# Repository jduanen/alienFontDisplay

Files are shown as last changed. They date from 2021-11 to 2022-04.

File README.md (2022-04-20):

# alienFontDisplay
Display made of six eight-segment EL display units with per-display custom driver board and controller.

Scrolling display board that displays whatever string is published on a given MQTT channel over WiFi.

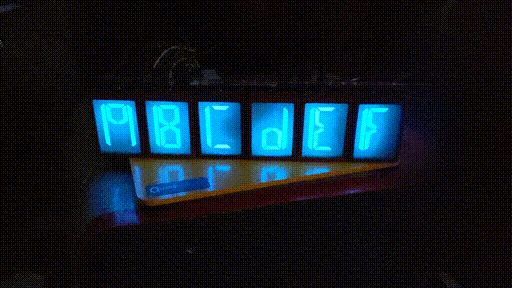
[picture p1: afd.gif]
Scroll Test


These displays were used in Russian tanks and missile launch consoles.

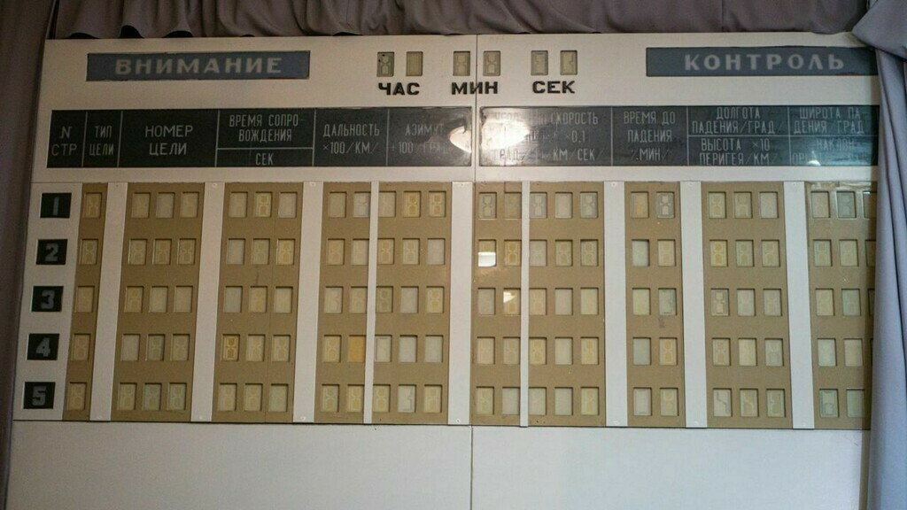
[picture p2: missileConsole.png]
Missile Console


## TBD
* Design 225VAC 400Hz inverter that can supply ?mA (?W)
* BOM
* WiFi interface board
* Firmware
* Tests
* Example code
* Documentation

### Display Pinout
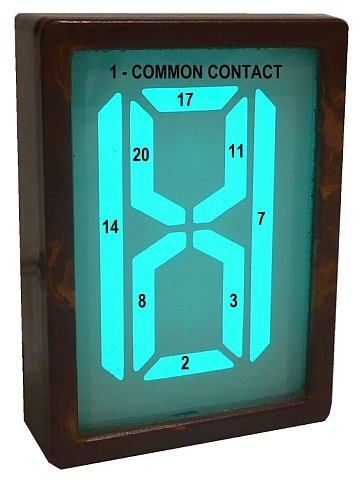
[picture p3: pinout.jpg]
EL Display Pinout


### Alphanumeric Font
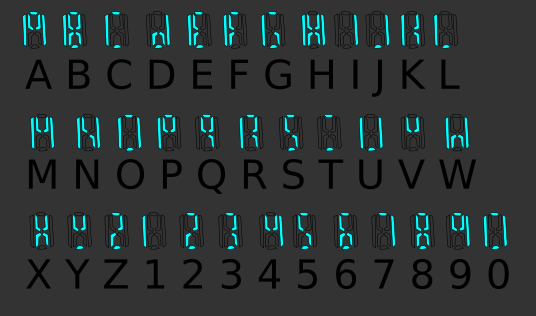
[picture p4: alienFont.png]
Alien Font


### Single Display and Driver Board
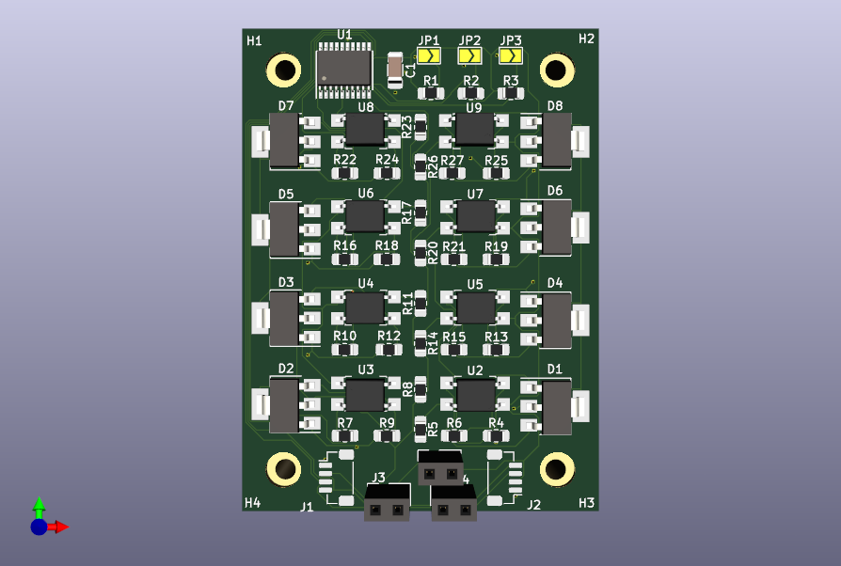
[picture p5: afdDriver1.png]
Driver Board view #1

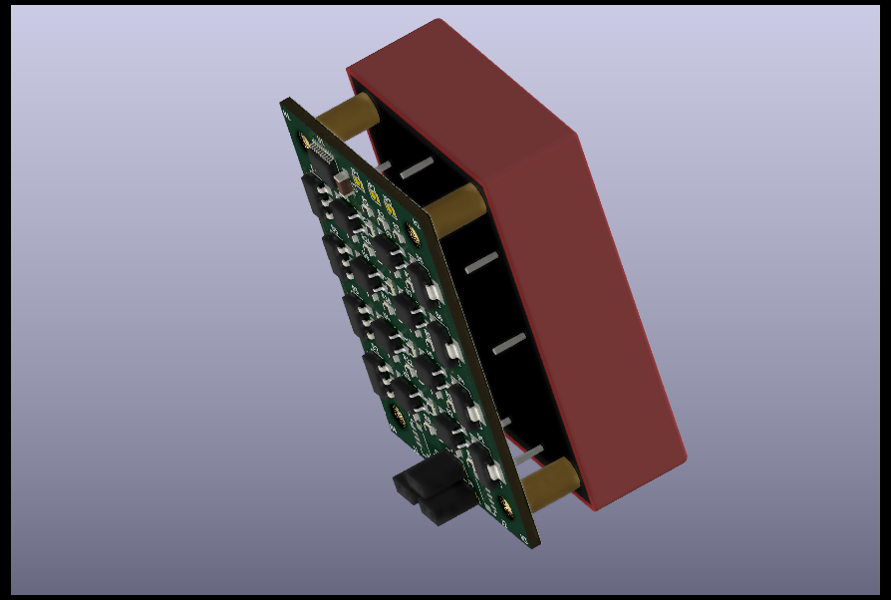
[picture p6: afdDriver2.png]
Driver Board view #2


### Driver PCB
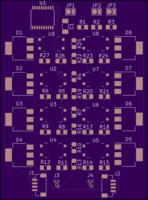
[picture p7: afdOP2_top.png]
Driver Board Top

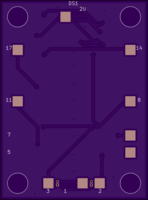
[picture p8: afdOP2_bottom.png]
Driver Board Bottom

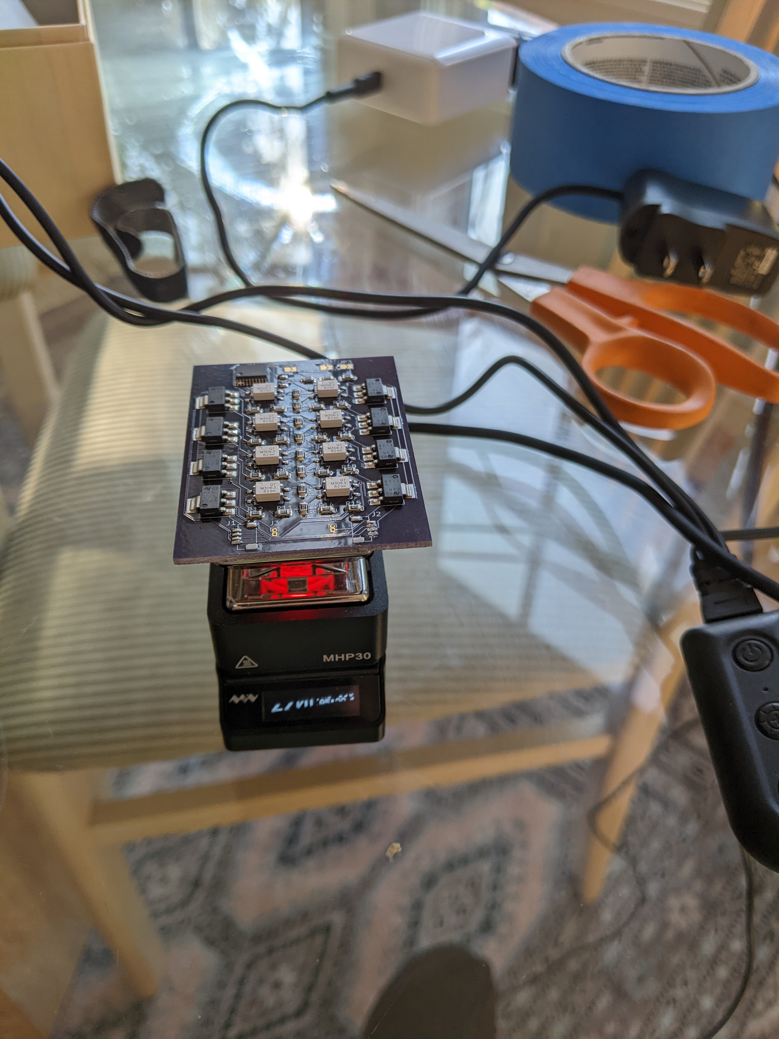
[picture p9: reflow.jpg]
Assembling Board

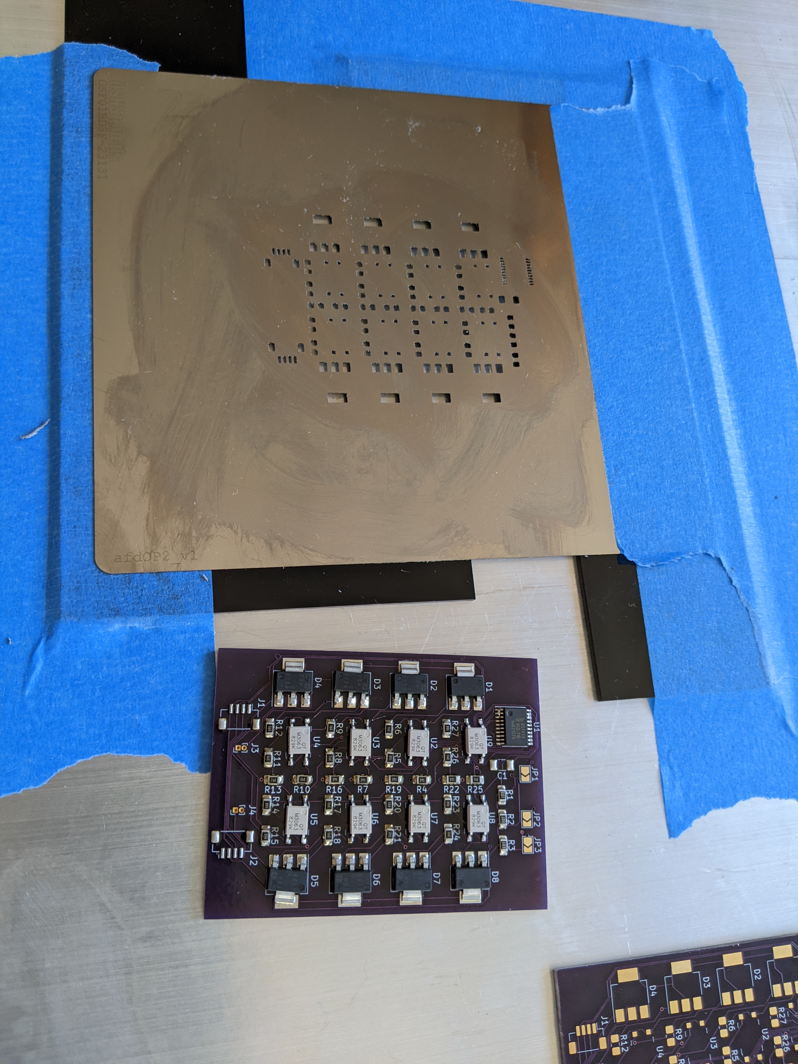
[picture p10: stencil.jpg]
Assembled Board


### Schematic
Driver Board Schematic

# EL Displays

## IEL-O-VI C63.396.208-02
* Blue, Alien Font, Russian/Soviet Electroluminescent Display
* [0-9] and [A-Z] (after a fashion)
  - some characters are lower case and some are missing strokes
    * in particular, there isn't a center vertical stroke, so "T" and "I" are not so great
  - seems to have been designed for Cyrillic characters
* pinout
  - 1: common
  - 2: bottom horizontal (S)
  - 3: bottom right angled (M)
  - 5: n/c?
  - 7: left vertical (L)
  - 8: bottom left angled (M)
  - 11: top right angled (M)
  - 14: left vertical (L)
  - 17: top horizontal (S)
  - 20: top left angled (M)
* per-segment capacitance (estimates)
  - S (2x): 55 pFd
  - M (4x): 90 pFd
  - L (2x): 170 pFd

# Power Supply Design

* Specs
  - 220VAC @ 400Hz
  - 0.5-3mA per display
    * four displays: 12mA (max)
    * six displays: 18mA (max)
* Design alternatives
  - drive audio amp into (CT?) step-up transformer
  - DC boost converter into H-Bridge

=========================

* notes
  - ~200V @ 400Hz
  - not squarewave -- filter or triangle wave for constant dv/dt
  - less bright at 50Hz, but last longer
  - need current limiting resistor if power source has low internal resistance
    * e.g., 330K ohm @ 220V @ 50Hz
  - 500 Hrs lifespan
  - sine/square voltage up to 250V and 400Hz-5KHz
  - decay time fractions of msec
  - at least 6usec pulse
  - no loss of brightness in pulses of 100usec at constant duty cycle
  - most of drop in brightness occurs in first 200 hours of operation
    * relatively flat after that
  - for best lifetime, maintain constant frequency and reduce voltage
  - use current limiting resistor for supplies with internal resistance less than 1Kohm
  - add 0.03-0.05ufd caps in parallel with electrodes to improve reliability
  - nomenclature
    * I: indicator
    * EL: electroluminescent
    * color
      - O: one color
      - M: multicolor
      - P: raster
    * size (13x sizes)
      - VI: 34x40mm
      - II: 13x35mm
      - IV: 18x26mm
      - 
    * number of dots indicate brightness
  - IEL-0-VI-101-246: 19x segment starburst with bar above and left and right commas
  - constant power mode
    * 220V @ 400Hz
  - constant brightness mode
    * 175-250V @ 1200Hz -- increases with service life
  - 0.5-3 mA current
  - DC will destroy the display
  - can't multiplex displays -- need driver for each segment
  - lifetime drops rapidly with supply frequency >400Hz

* Links
  - https://www.nixology.uk/el-displays/
  - http://www.155la3.ru/electroluminescent.htm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
  - https://www.youtube.com/watch?v=p6mNbgtnFK8
  - http://lampes-et-tubes.info/cd/cd143.php?l=e
  - http://www.nedopc.org/forum/viewtopic.php?f=65&t=11093
  - https://www-nedopc-org.translate.goog/forum/viewtopic.php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

* Sparkfun EL Inverter (COM-10469 retired)
  - input: 12VDC
  - output: 70-110V (90V typ)
  - frequency: 800-3500Hz (2000Hz typ)

* Sparkfun EL Inverter (sourced from Amazon)
  - input: 5VDC
  - output: 225VAC (in afd circuit)
  - frequency: 5-7KHz (in afd circuit)

=======================================================================================
* SmartSocket for Alien Font displays
  - use same protocol on daisy-chained 9600 baud RS232 (3v3?)
    * http://tayloredge.com/reference/Circuits/1386SmartSocket/SmartSockets.pdf
  - build single-sided PCB that fits on back of display units
    * drive each segment individually
    * use common HV PSU
    * use circuits from SparkFun boards as they have been tested and shown to work
  - need to select a PIC to use as the on-board controller
    * PIC18F16Q41: same as PIC18F16Q40 but has an opAmp
    * PIC18F16Q40:
      - 14pin device has six GPIOs on PortA and another six on PortC
      - has 1/2 UARTs
      - 64KB program FLASH, 4KB SRAM, 512B EEPROM
      - 18x GPIO, 2/3x 8b timers, 17x channels of 12b ADC, 2x 8b DACs, 4x DMA
      - 32b CRC with scanner, vectored interrupts, temperature indicator, NCO, PWM/CCP
      - C compiler
        * CCS: http://www.ccsinfo.com -- $200-$500
        * Hi-Tech: http://www.htsoft.com -- bought by Microchip
        * Microchip: http://www.microchip.com -- free student mode
        * MPLAB C18: microchip
        * MikroC: free student version with limits
        * https://www.microchip.com/en-us/development-tool/C18
      - $1.5 at Mouser (in stock)
        * PIC18F16Q40-E/SO
        * https://www.mouser.com/ProductDetail/Microchip/PIC18F16Q40-E-SO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
      - example: https://github.com/microchip-pic-avr-examples/pic18f16q40-quadrature-decoder
        * RA2: UART Tx programmer?
        * RB7: UART Tx
        * RB5: UART Rx
        * RB4, RB6, RA4, RA5, RC0-RC7: GPIO
      - PPS re-mappable input signals can be moved from default locations to other ports
        * UART outputs: DTR1, RTS1, TX1, DTR2, RTS2, TX2, DTR3, RTS3, TX3
        * UART inputs: RX1, CTS1, RX2, CTS2, RX3, CTS3 
      - pin allocation table (default)
        * RB5: RX1
        * RB7: CTS1
        * RC1: RX2
        * RC2: CTS2
        * RC3: RX3
        * RC5: CTS3
  - use shift registers?
  - use I2C port expander?

* display unit dimensions, pin and threaded spacer locations are not consistent across instances

* Use SparkFun EL boards for proof of concept testing

* EL Sequencer v23
  - https://www.sparkfun.com/products/12781
  - http://cdn.sparkfun.com/datasheets/Components/EL/SparkFun_EL_Sequencer_v23.pdf
  - ATMega328P processor on-board
    * use "Arduino Duemilanove or Diecimila" board with FTDI USB dongle
  - Gets HV from Sparkfun EL Inverter
    * not ideal -- need higher voltage and better frequency
  - Drives HV to all segments of all displays
    * EL Escudo Dos pulls display commons to HV_GND
  - D2-D9 used to drive EL_A-EL_H
    * EL_A: pin 2
    * EL_B: pin 3
    * EL_C: pin 7
    * EL_D: pin 8
    * EL_E: pin 11
    * EL_F: pin 14
    * EL_G: pin 17
    * EL_H: pin 20
  - Sends six (active high) TTL signals to EL Escudo Dos to enable each display
    * ADC_0 (JP4:2): display #1
    * ADC_1 (JP4:7): display #2
    * ADC_2 (JP2:8): display #3
    * ADC_3 (JP2:7): display #4
    * ADC_4 (JP2:6): display #5
    * ADC_5 (JP2:5): display #6

* EL Escudo Dos
  - https://www.sparkfun.com/products/10878
  - https://cdn.sparkfun.com/datasheets/Components/EL/EL_Escudo_Dos/EL%20Escudo%20Dos%20v21.pdf
  - Pulls display common lines (pin 1) down to HV_GND
  - EL_H: display #1 ... EL_C: display #6
  - gets HV_GND and TTL display unit selector signals from EL Sequencer
  - all SCRs have common HV connected to their tabs
    * and they have individual outputs to load and ground
  - need to cut HV to tabs and connect them to the display common signals
    * and short all load outputs to HV_GND

* misc
  - mqtt listener
    * mosquitto_sub -t /displays/# -F "%I,%t,%p"
  - commands
    * rssi
    * version
    * reset
    * rate[=<rate>]
    * scrollDelay[=<msecs>]
    * pause[=<msecs>]
    * display[=<str>]
  - e.g., mosquitto_pub -t "/displays/afd/<IPAddr>/cmd" -m "display=abcdefghijklmnopqrstuvwxyz0123456789"

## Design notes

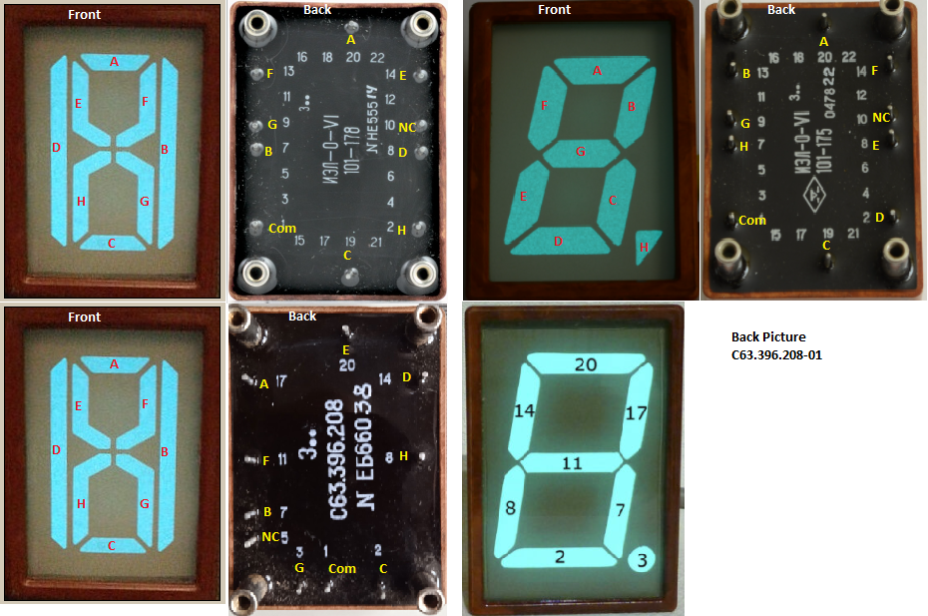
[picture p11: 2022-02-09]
elpanel.png

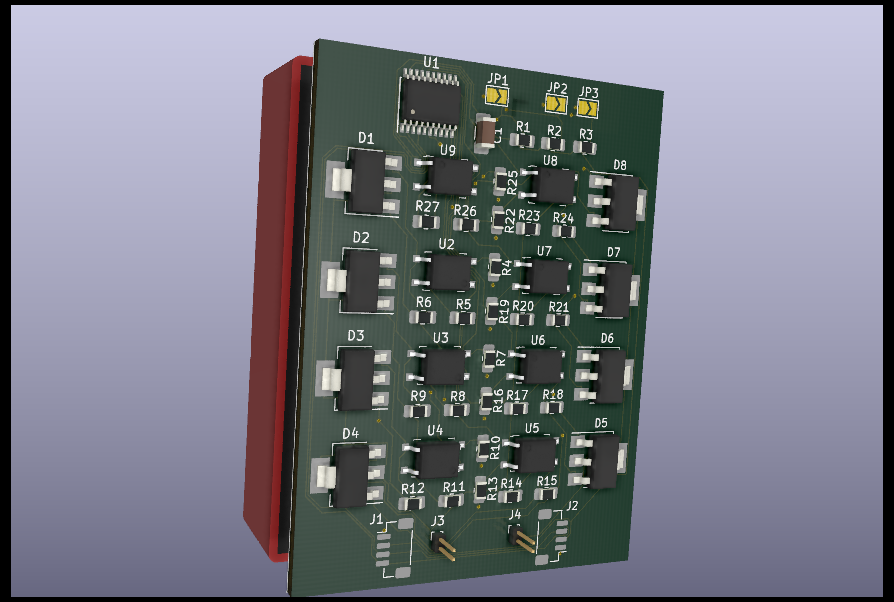
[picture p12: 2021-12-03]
board/afdDriverOP2/afdDriver2Layer2.png

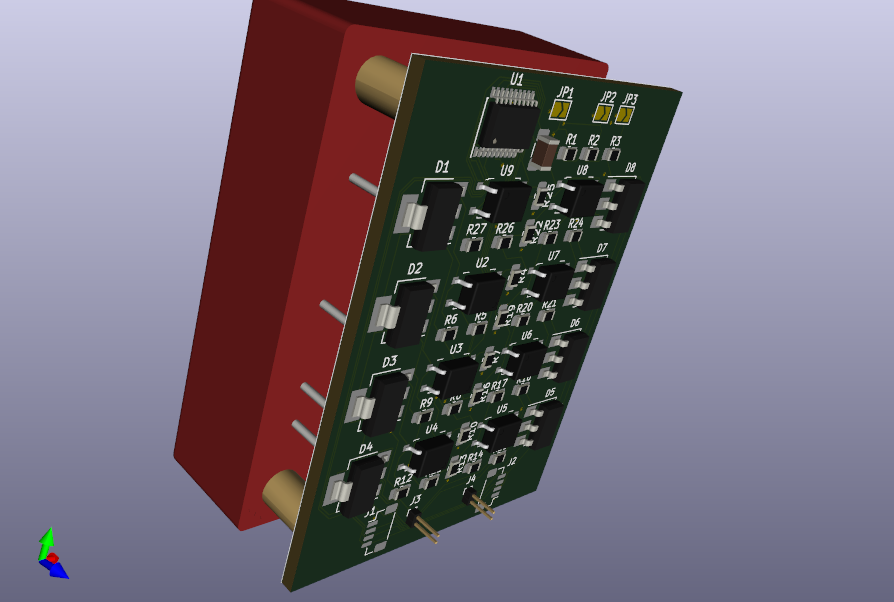
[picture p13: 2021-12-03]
board/afdDriverOP2/afdDriver2Layer1.png

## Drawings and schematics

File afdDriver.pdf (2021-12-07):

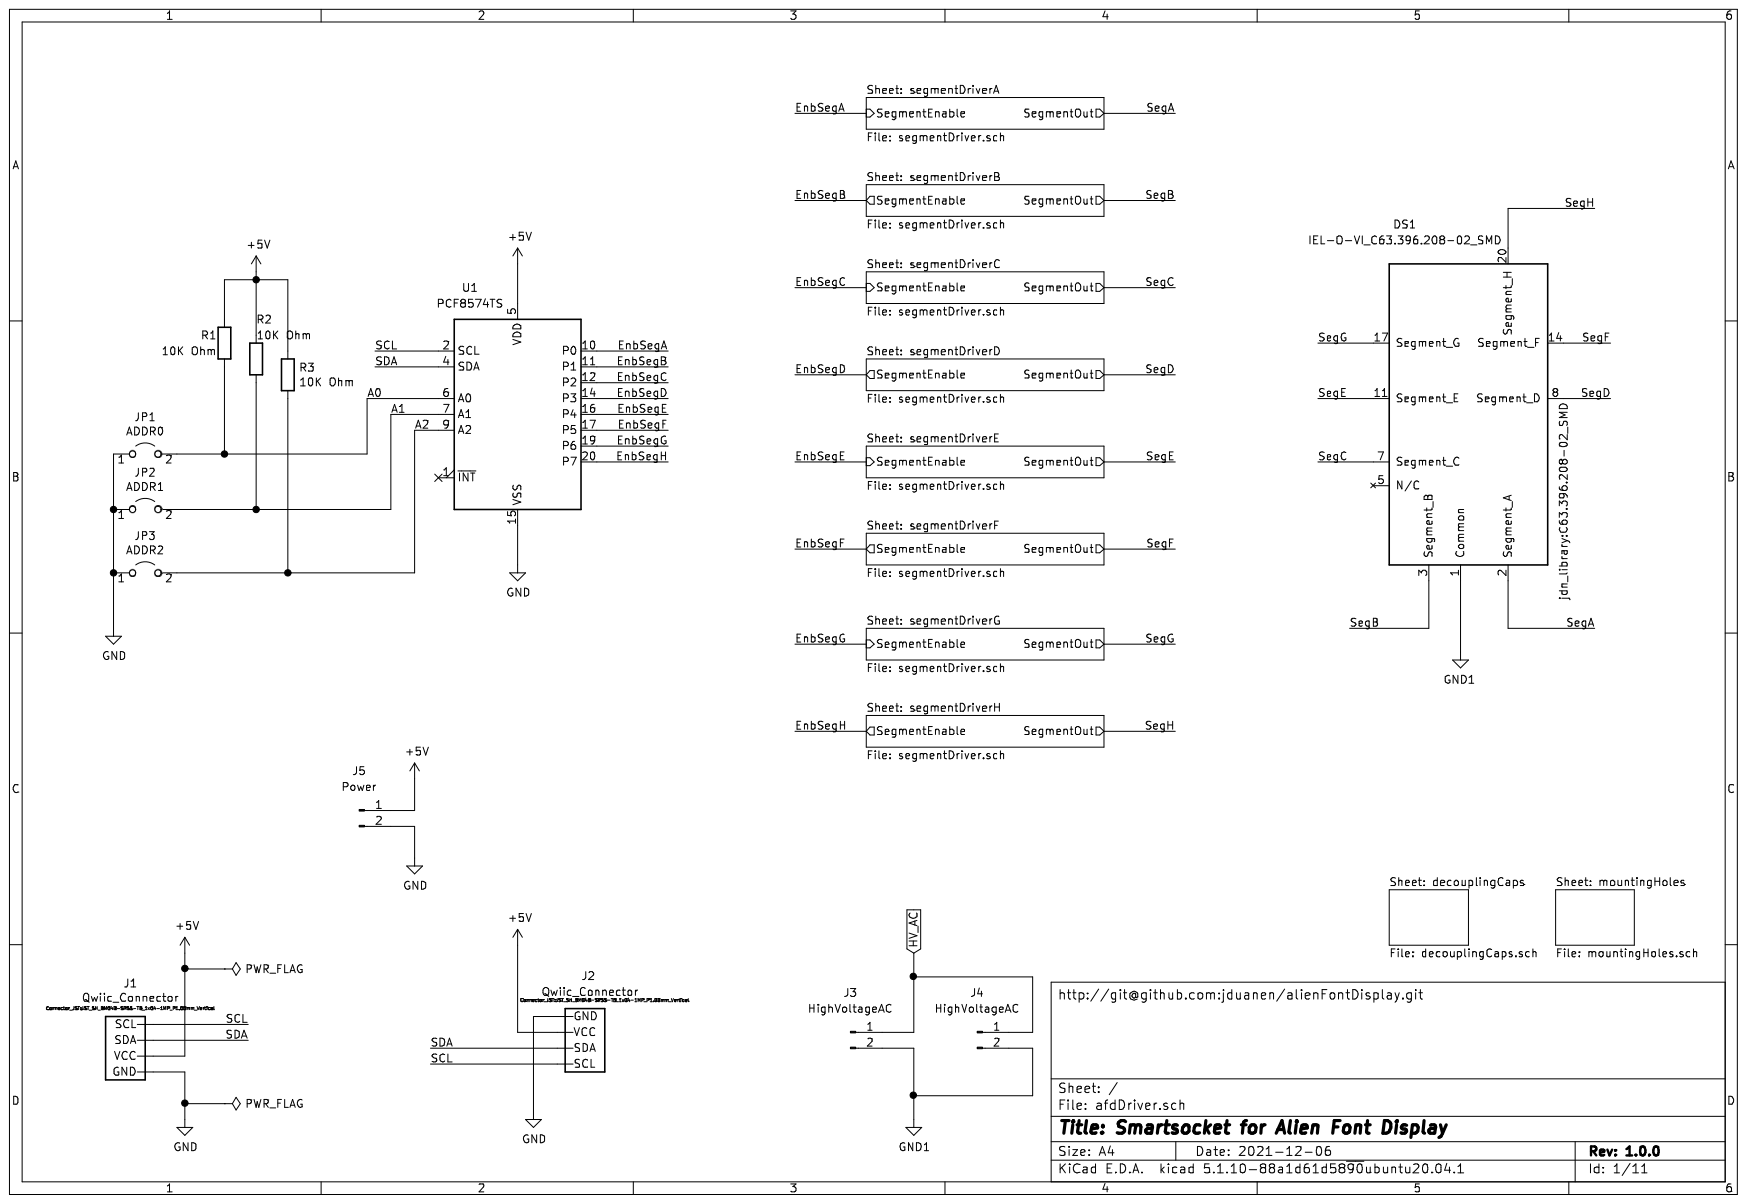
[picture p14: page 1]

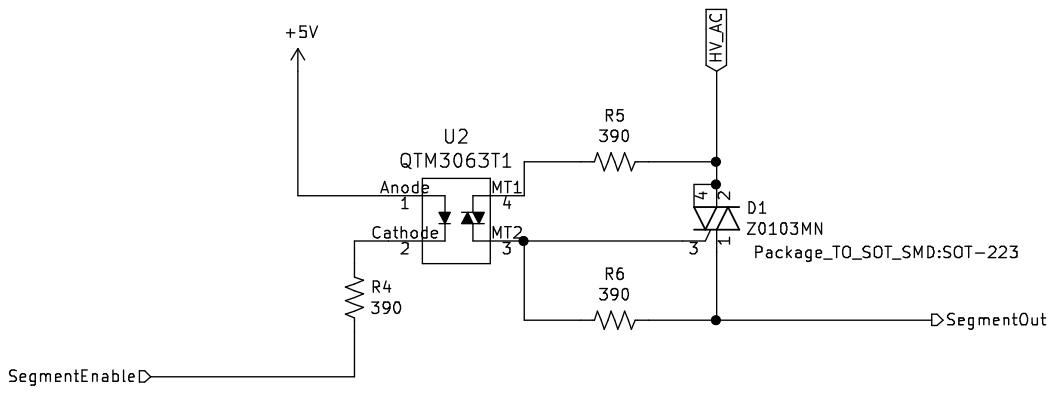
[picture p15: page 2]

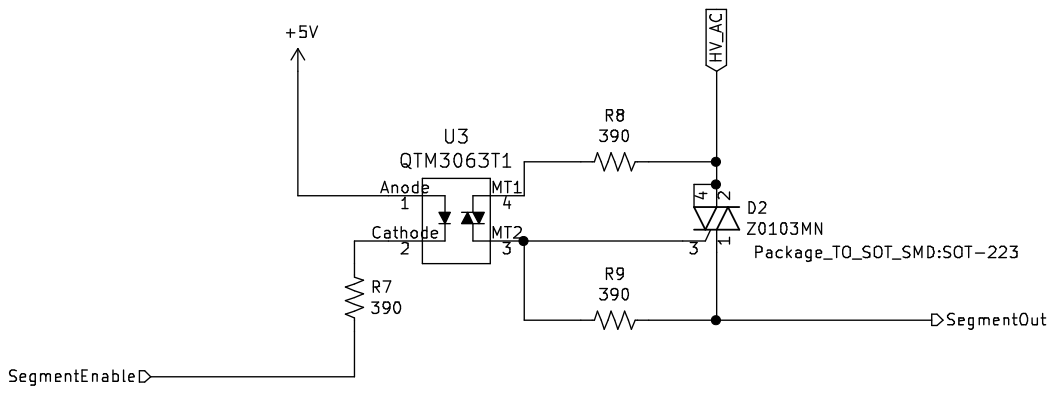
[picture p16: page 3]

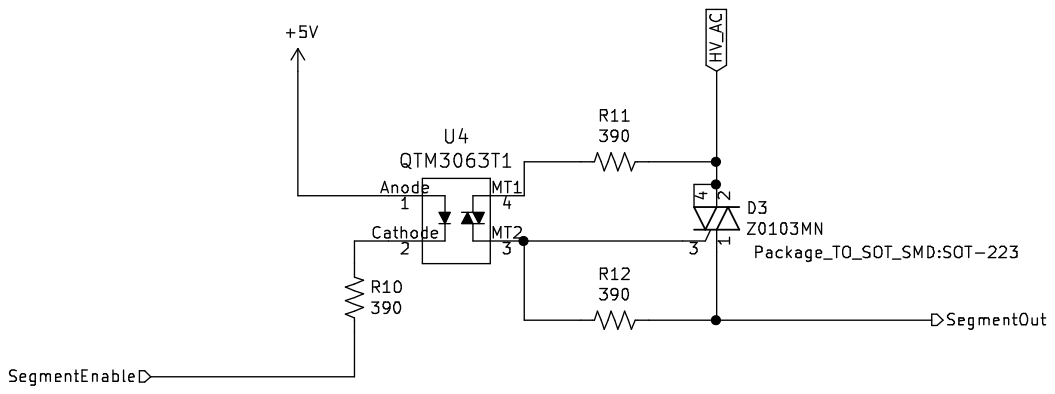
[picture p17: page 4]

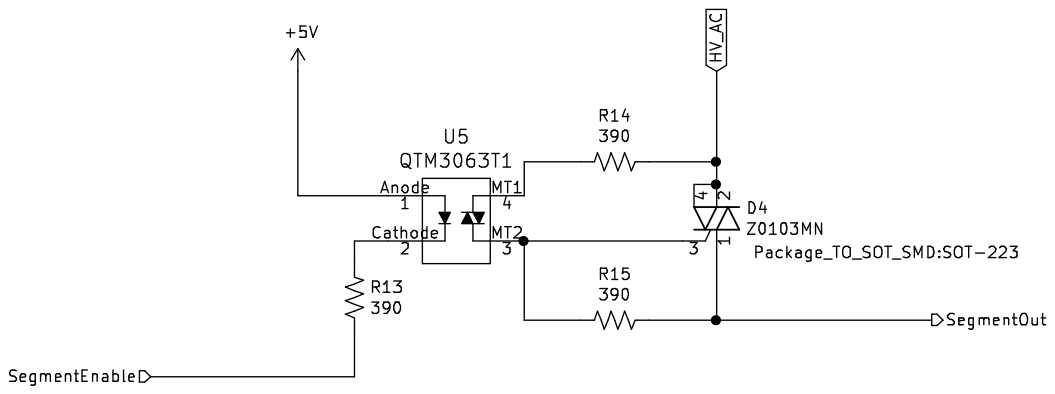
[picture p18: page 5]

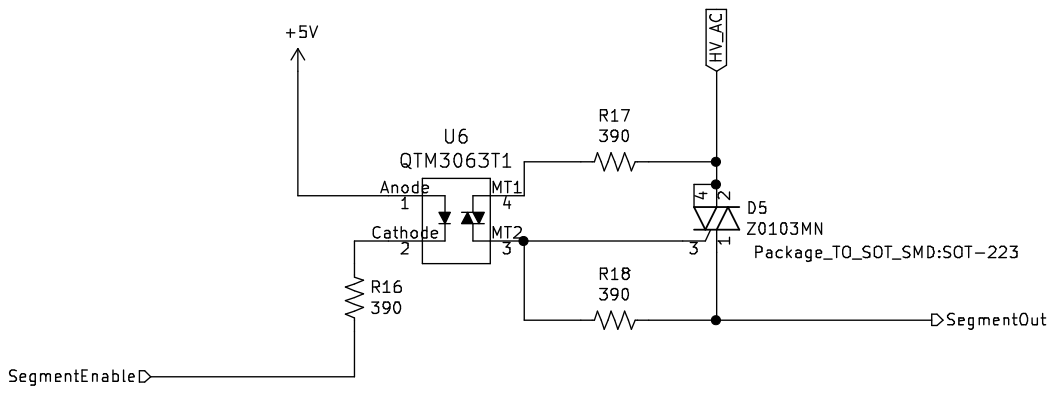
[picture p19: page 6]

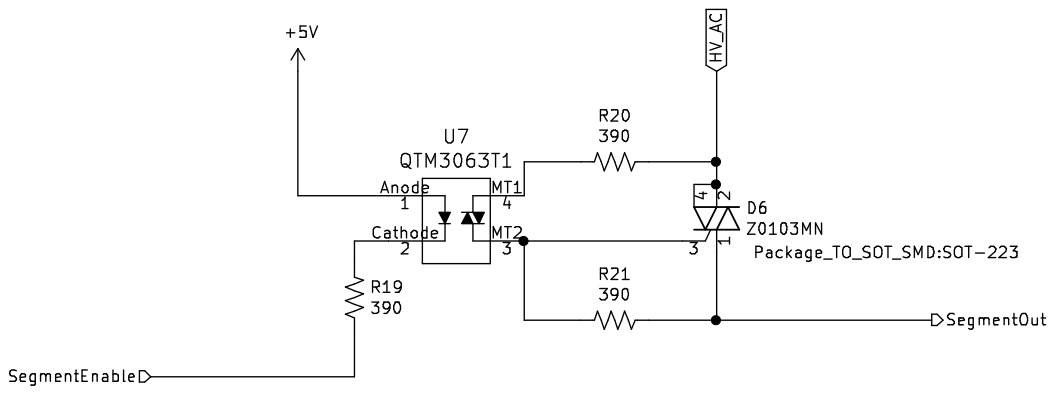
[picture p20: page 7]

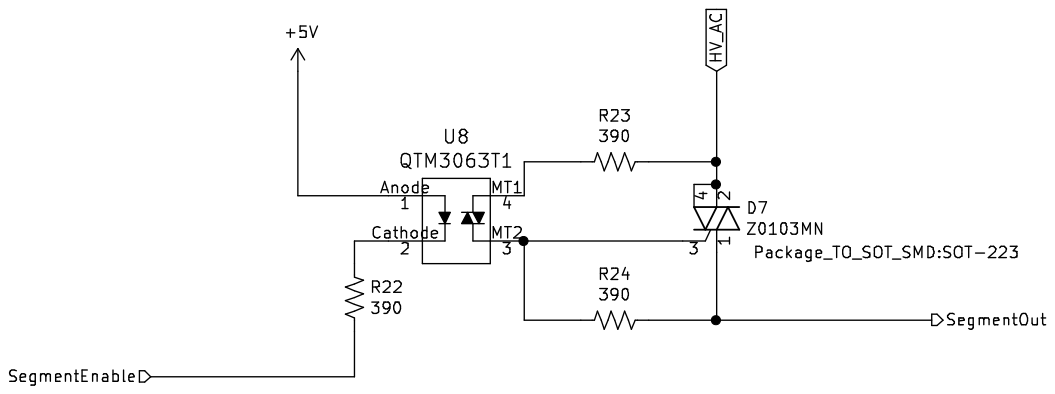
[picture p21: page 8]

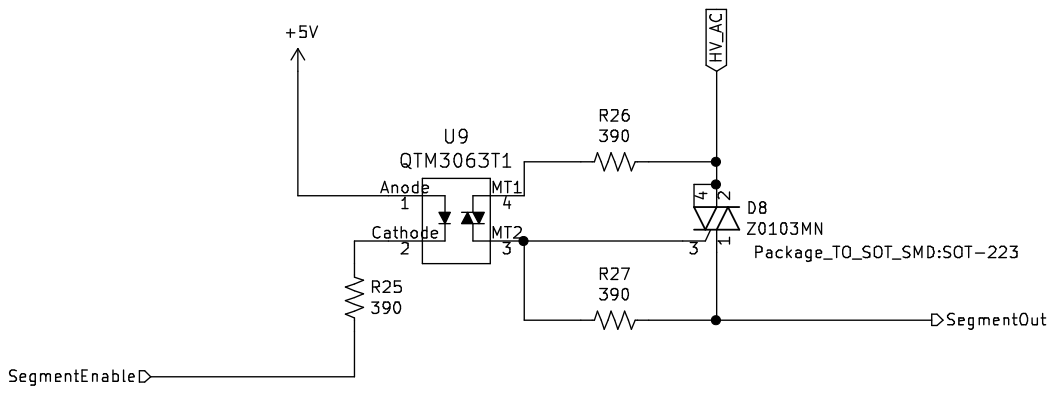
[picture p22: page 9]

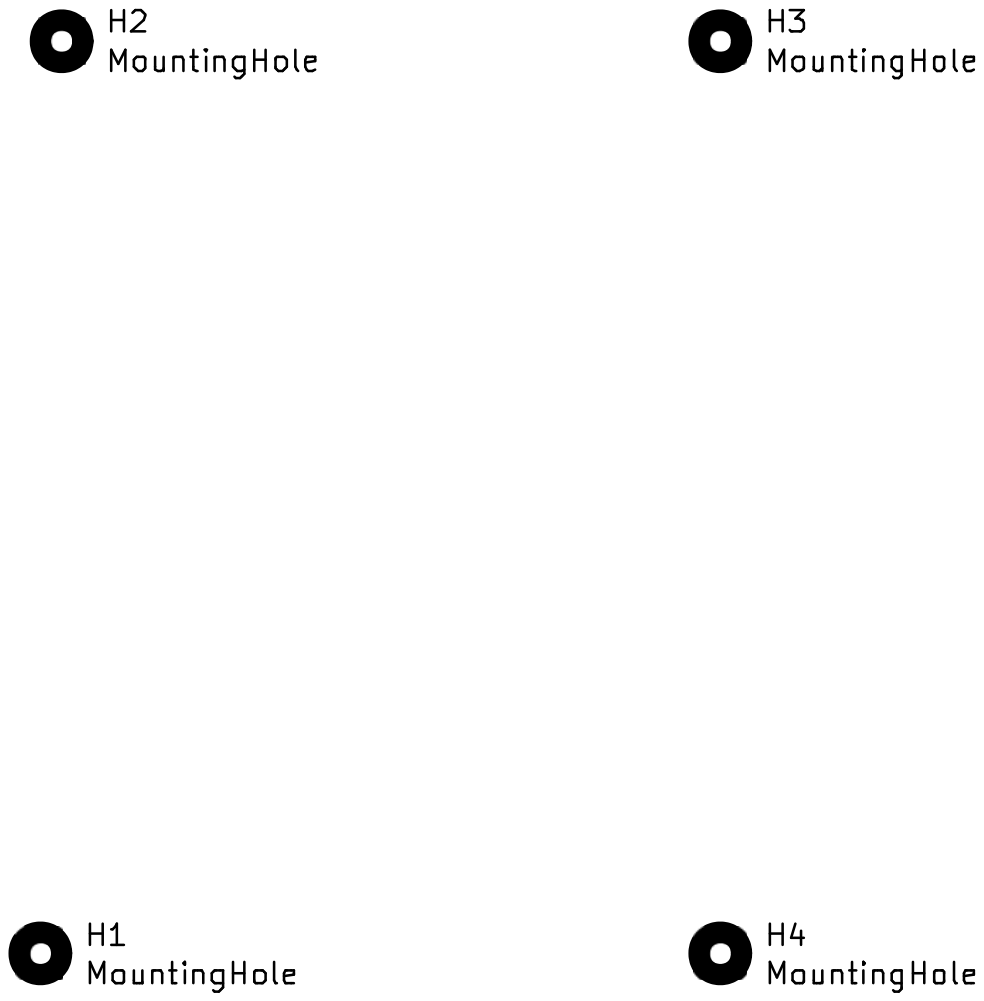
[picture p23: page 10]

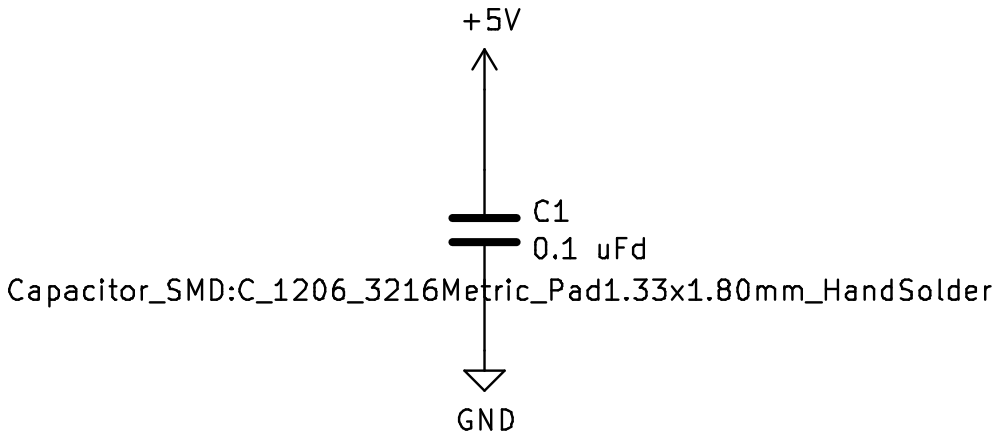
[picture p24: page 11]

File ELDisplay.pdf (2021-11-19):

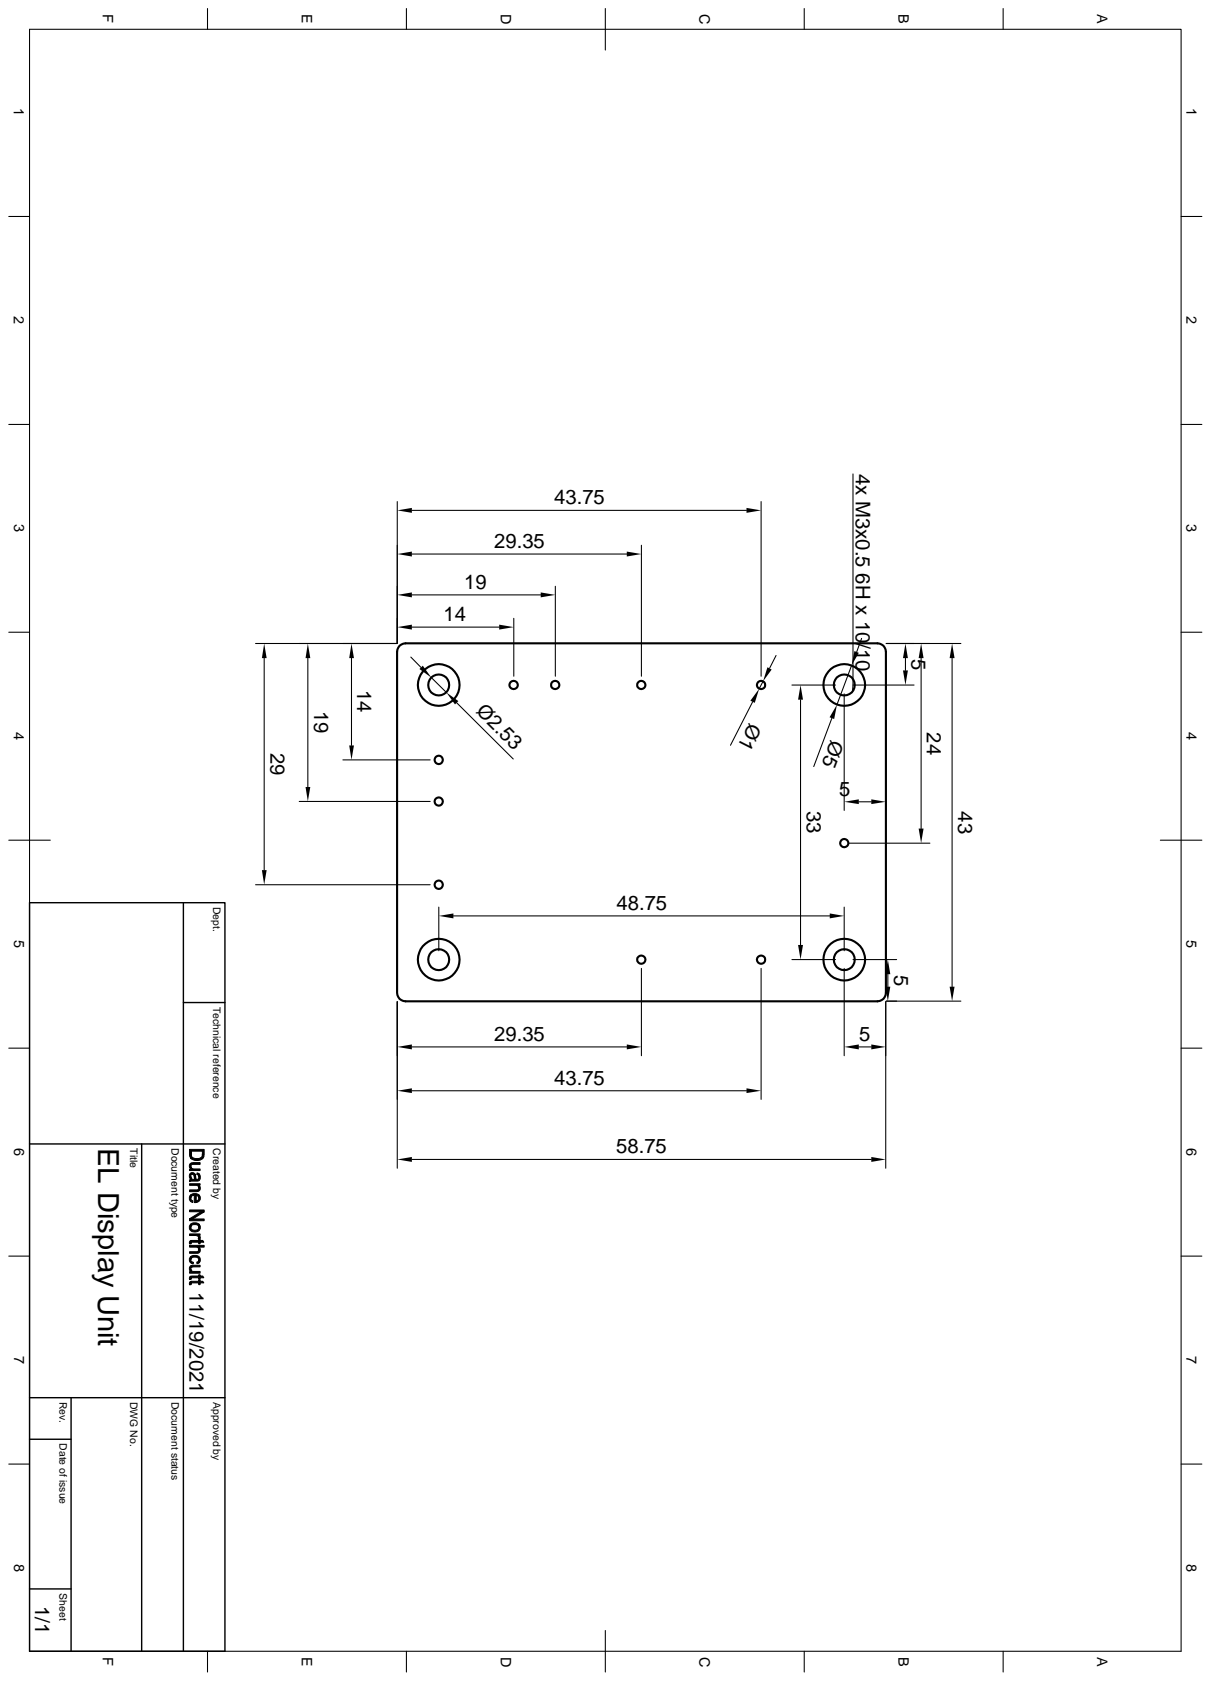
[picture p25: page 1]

1 A 2 3 4 5 6 7 8 1 2 3 4 5 6 7 8 FEDCB FEDCBA Dept. Technical reference Created by Approved by Document type Document status Title Rev. DWG No.Date of issue Sheet 11/19/2021 1/1 EL Display Unit 24 43















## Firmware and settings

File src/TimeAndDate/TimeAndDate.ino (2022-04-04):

/***************************************************************************
 *
 * AFD Time and Date Display Application
 *
 * Uses SensorNet MQTT and displays what is published on its topic
 *
 ***************************************************************************/

#include <Arduino.h>
#include <PCF8574.h>
#include "SensorNet.h"
#include "wifi.h"
#include "AFD.h"


#define VERBOSE             1
#define APP_NAME            "AFD"
#define APP_VERSION         "1.2.0"
#define REPORT_SCHEMA       "scrollDelay:d,pause:d,display:s,rssi:d"
#define TOPIC_PREFIX        "/displays/afd"
#define MQTT_SERVER         "192.168.166.113"
#define MQTT_PORT           1883


SensorNet sn(APP_NAME, APP_VERSION, REPORT_SCHEMA);

AFD afd = AFD();

// Callback function header
callback myCallback;

void print(String s) {
  if (VERBOSE) {
    sn.consolePrint(s);
  }
}

void println(String s) {
  if (VERBOSE) {
    sn.consolePrintln(s);
  }
}

void myCallback(char* topic, byte* payload, unsigned int length) {
  String respMsg;
  char msgType = SensorNet::RESPONSE;
  SensorNet::callbackMessage cbMsg = sn.baseCallback(topic, payload, length);

  if (cbMsg.handled == true) {
    println("Callback message handled by baseCallback");
    // N.B. you can do other stuff in addition to what's done in the base hander here
  } else {
    if (cbMsg.cmd.equalsIgnoreCase("pause")) {
      int pause;
      if (cbMsg.val != NULL) {
        pause = cbMsg.val.toInt();
        if (pause < 0) {
          println("Error: pause value must be positive, using default value");
          pause = DEF_PAUSE;
        }
        afd.setPause(pause);
      }
      respMsg = "pause=" + String(afd.getPause());
    } else if (cbMsg.cmd.equalsIgnoreCase("scrollDelay")) {
      int scrollDelay;
      if (cbMsg.val != NULL) {
        scrollDelay = cbMsg.val.toInt();
        if (scrollDelay < 0) {
          println("Error: scrollDelay value must be positive, using default value");
          scrollDelay = DEF_SCROLL_DELAY;
        }
        afd.setScrollDelay(scrollDelay);
      }
      respMsg = "scrollDelay=" + String(afd.getScrollDelay());
    } else if (cbMsg.cmd.equalsIgnoreCase("display")) {
      if (cbMsg.val != NULL) {
        afd.displayStr = String(cbMsg.val);
        afd.displayStr.toUpperCase();
      }
      respMsg = "display=" + afd.displayStr;
    } else {
      respMsg = "ERROR: unknown command (" + cbMsg.cmd + ")";
      msgType = SensorNet::ERROR;
    }
    println("Response Message: " + respMsg);
    sn.mqttPub(msgType, respMsg);
  }
}

void setup() {
  sn.serialStart(&Serial, 9600, true);
  delay(500);
  println(APP_NAME);

  sn.wifiStart(WLAN_SSID, WLAN_PASS);
  println("WIFI");

  sn.mqttSetup(MQTT_SERVER, MQTT_PORT, TOPIC_PREFIX, myCallback);
  println("MQTT");
}

#define WAIT_TIME 3000

unsigned int indx = 0;

#define NUM_STRS  10

void loop() {
  String msg;
  unsigned long now = millis();
  unsigned long deltaT = now - sn.lastReport;

  sn.mqttRun();

  if (deltaT >= sn.reportInterval) {
    msg = String(afd.getPause()) + "," + String(afd.getScrollDelay()) + "," + afd.displayStr + "," + String(sn.wifiState().rssi);

    sn.mqttPub(SensorNet::DATA, msg);
    println("Status Msg: " + msg);
    sn.lastReport = now;
  }

  afd.printStr(afd.displayStr);
  indx++;
  if (indx >= NUM_STRS) {
    indx = 0;
    delay(WAIT_TIME);

    println("Reset");
  }
  println("Loop");
};

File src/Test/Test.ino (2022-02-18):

/***************************************************************************

 AFD Test Program
 
****************************************************************************/

#include "Arduino.h"
#include "PCF8574.h"

// TODO invert binary values in tables and remove negation in code

#define TEST            1
#define VERBOSE         1

#define I2C_BASE_ADDR   0x20
#define READ_ADDR       0x4F
#define WRITE_ADDR      0x4E
#define NUM_UNITS       6
#define NUM_SEGMENTS    8
#define CHAR_MAP_SIZE   26
#define DIGIT_MAP_SIZE  10


unsigned char c = 0;

PCF8574 afd[NUM_UNITS] = {
  PCF8574(I2C_BASE_ADDR),
  PCF8574(I2C_BASE_ADDR + 1),
  PCF8574(I2C_BASE_ADDR + 2),
  PCF8574(I2C_BASE_ADDR + 3),
  PCF8574(I2C_BASE_ADDR + 4),
  PCF8574(I2C_BASE_ADDR + 5)
};

unsigned char charMap[CHAR_MAP_SIZE] = {
  0b00000100 + 0b00010000 + 0b00100000 + 0b01000000 + 0b10000000, // A
  0b00000001 + 0b00000010 + 0b00001000 + 0b00010000 + 0b00100000 + 0b01000000 + 0b10000000, // B
  0b00000001 + 0b00100000 + 0b01000000, // C
  0b00000001 + 0b00000010 + 0b00000100 + 0b00001000, // d
  0b00000001 + 0b00001000 + 0b00100000 + 0b01000000 + 0b10000000, // E
  0b00001000 + 0b00100000 + 0b01000000 + 0b10000000, // F
  0b00000001 + 0b00000010 + 0b00100000 + 0b01000000, // G
  0b00000010 + 0b00000100 + 0b00001000 + 0b00010000 + 0b00100000 + 0b10000000, // H
  0b00000100, // I
  0b00000001 + 0b00000100, // J
  0b00000010 + 0b00010000 + 0b00100000, // K
  0b00000001 + 0b00100000, // L
  0b00000100 + 0b00010000 + 0b00100000 + 0b10000000, // M
  0b00000010 + 0b00000100 + 0b00100000 + 0b10000000, // N
  0b00000001 + 0b00000100 + 0b00100000 + 0b01000000, // O
  0b00010000 + 0b00100000 + 0b01000000 + 0b10000000, // P
  0b00000010 + 0b00010000 + 0b01000000 + 0b10000000, // q
  0b00000010 + 0b00010000 + 0b00100000 + 0b01000000, // R
  0b00000001 + 0b00000010 + 0b01000000 + 0b10000000, // S
  0b00000001 + 0b01000000, // T
  0b00000001 + 0b00000100 + 0b00100000, // U
  0b00010000 + 0b10000000, // v
  0b00000010 + 0b00000100 + 0b00001000 + 0b00100000, // W
  0b00000010 + 0b00001000 + 0b00010000 + 0b10000000, // X
  0b00000001 + 0b00010000 + 0b10000000, // Y
  0b00000001 + 0b00001000 + 0b00010000 + 0b01000000 // Z
};

unsigned char digitMap[DIGIT_MAP_SIZE] = {
  0b00000001 + 0b00000100 + 0b00100000 + 0b01000000, // 0
  0b00100000, // 1
  0b00000001 + 0b00001000 + 0b00010000 + 0b01000000, // 2
  0b00000001 + 0b00000010 + 0b00010000 + 0b01000000, // 3
  0b00000100 + 0b00010000 + 0b10000000, // 4
  0b00000001 + 0b00000010 + 0b01000000 + 0b10000000, // 5
  0b00000001 + 0b00000010 + 0b00001000 + 0b01000000 + 0b10000000, // 6
  0b00000100 + 0b01000000, // 7
  0b00000001 + 0b00000010 + 0b00001000 + 0b00010000 + 0b01000000 + 0b10000000, // 8
  0b00000100 + 0b00010000 + 0b01000000 + 0b10000000 // 9
};


void condPrint(String s) {
  if (VERBOSE) {
    Serial.print(s);
  }
}


void condPrintln(String s) {
  if (VERBOSE) {
    Serial.println(s);
  }
}


void clearUnit(unsigned char unit) {
  unsigned char seg;
  for (seg = 0; seg < NUM_SEGMENTS; seg++) {
    afd[unit].digitalWrite(seg, HIGH);
  }
}


void clearAllUnits() {
  unsigned char unit;
  for (unit = 0; unit < NUM_UNITS; unit++) {
    clearUnit(unit);
  }
}


void setup() { 
  unsigned char unit;

  Serial.begin(9600);
  delay(500);

  for (unit = 0; unit < NUM_UNITS; unit++) {
    afd[unit].pinMode(P0, OUTPUT, HIGH);
    afd[unit].pinMode(P1, OUTPUT, HIGH);
    afd[unit].pinMode(P2, OUTPUT, HIGH);
    afd[unit].pinMode(P3, OUTPUT, HIGH);
    afd[unit].pinMode(P4, OUTPUT, HIGH);
    afd[unit].pinMode(P5, OUTPUT, HIGH);
    afd[unit].pinMode(P6, OUTPUT, HIGH);
    afd[unit].pinMode(P7, OUTPUT, HIGH);
    afd[unit].begin();
  }
  clearAllUnits();

  condPrintln("Start");
}


void writeDigit(unsigned char unit, unsigned char digit) { 
  unsigned char chr;
  PCF8574::DigitalInput digitalInput;

  chr = digitMap[digit % DIGIT_MAP_SIZE];
  digitalInput.p7 = !((chr >> 7) & 0x01);
  digitalInput.p6 = !((chr >> 6) & 0x01);
  digitalInput.p5 = !((chr >> 5) & 0x01);
  digitalInput.p4 = !((chr >> 4) & 0x01);
  digitalInput.p3 = !((chr >> 3) & 0x01);
  digitalInput.p2 = !((chr >> 2) & 0x01);
  digitalInput.p1 = !((chr >> 1) & 0x01);
  digitalInput.p0 = !((chr >> 0) & 0x01);

  afd[unit % NUM_UNITS].digitalWriteAll(digitalInput);
  condPrint("writeDigit: 0x" +  String(chr, HEX) + "; ");
}


void writeChar(unsigned char unit, unsigned char character) { 
  unsigned char chr;
  PCF8574::DigitalInput digitalInput;

  chr = charMap[character % CHAR_MAP_SIZE];
  digitalInput.p7 = !((chr >> 7) & 0x01);
  digitalInput.p6 = !((chr >> 6) & 0x01);
  digitalInput.p5 = !((chr >> 5) & 0x01);
  digitalInput.p4 = !((chr >> 4) & 0x01);
  digitalInput.p3 = !((chr >> 3) & 0x01);
  digitalInput.p2 = !((chr >> 2) & 0x01);
  digitalInput.p1 = !((chr >> 1) & 0x01);
  digitalInput.p0 = !((chr >> 0) & 0x01);

  afd[unit % NUM_UNITS].digitalWriteAll(digitalInput);
  condPrint("writeChar: 0x" +  String(chr, HEX) + "; ");
}
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

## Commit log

2021-11-18 Changed to one segmentDriver sheet.
    [afd.kicad_pcb, afd.sch]
2021-11-19 Put regulator on root page. Replicated segment driver child page.
    [afd.sch, segmentDriver.sch]
2021-11-22 Redrew schematic using labels.
    [afd.sch, segmentDriver.sch]
2021-11-22 Fixed DRC errors.
    [afd.sch]
2021-11-23 Before circuit change.
    [afd.kicad_pcb, afd.sch, segmentDriver.sch]
2021-11-23 Removed regulator.
    [afd.sch, segmentDriver.sch]
2021-11-23 Final attempt at single board.
    [afd.kicad_pcb, segmentDriver.sch]
2021-11-23 Changed optoisolator to smaller package.
    [afdDriver.kicad_pcb, afdDriver.sch, segmentDriver.sch]
2021-11-25 Added two ground posts.
    [afdDriver.kicad_pcb, afdDriver.sch, segmentDriver.sch]
2021-11-26 Checkpoint. Starting layout.
    [afdDriver.kicad_pcb]
2021-11-26 Checkpoint. New 3dmodels.
    [afdDriver.kicad_pcb]
2021-12-07 V1.0.0 design.
    [afdDriver.dsn, afdDriver.kicad_pcb, afdDriver.sch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]
2021-12-10 Embiggened +5V net.
    [afdDriver.kicad_pcb]
2021-12-12 Fixed B.Mask text.
    [afdDriver.kicad_pcb]
2021-12-12 Improved B.Silk layer on PCB. V1.0.1.
    [afdDriver.kicad_pcb, afdDriver.sch]
2021-12-12 Improved RefDes for DS1 on B.Silk
    [afdDriver.kicad_pcb]
2022-01-13 Added another test case.
2022-01-16 First cut.
2022-01-21 Fixed typo in report message.
    [TimeAndDate.ino]
2022-01-21 Ignore command case. Put RSSI at end of report. Bumped version.
2022-02-18 Converted to use conditional print.
